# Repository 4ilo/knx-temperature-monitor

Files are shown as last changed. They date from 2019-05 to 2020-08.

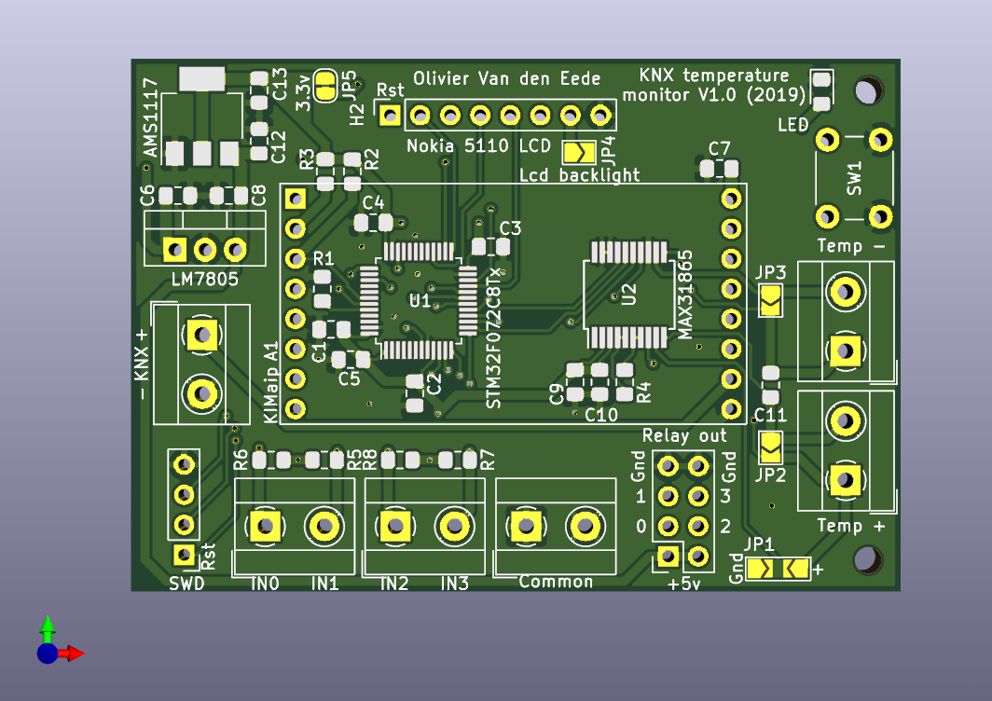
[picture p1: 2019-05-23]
pcb_v1.1/pcb.png

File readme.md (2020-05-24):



# KNX temperature monitor

Custom Pt100 temperature probe interface to KNX.

This module will be used to monitor my pool temperature, and generate alarms if the pump, water treatement or the pool heating stops.

### Features
- STM32F0 microcontroller
- On module LCD temperature readout (Nokia 5110 Lcd)
- Tapko KIMaip KNX bus interface module
- MAX31865 RTD-to-Digital Converter
- Extra binary I/O

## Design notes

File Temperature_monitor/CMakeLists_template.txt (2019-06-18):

#${templateWarning}
SET(CMAKE_SYSTEM_NAME Generic)
SET(CMAKE_SYSTEM_VERSION 1)
cmake_minimum_required(VERSION 3.7)

# specify cross compilers and tools
SET(CMAKE_C_COMPILER_WORKS 1)
SET(CMAKE_C_COMPILER arm-none-eabi-gcc)
SET(CMAKE_CXX_COMPILER_WORKS 1)
SET(CMAKE_CXX_COMPILER arm-none-eabi-g++)
set(CMAKE_ASM_COMPILER  arm-none-eabi-gcc)
set(CMAKE_AR arm-none-eabi-ar)
set(CMAKE_OBJCOPY arm-none-eabi-objcopy)
set(CMAKE_OBJDUMP arm-none-eabi-objdump)
set(SIZE arm-none-eabi-size)

SET(LINKER_SCRIPT $${CMAKE_SOURCE_DIR}/${linkerScript})

#Uncomment for hardware floating point
#SET(FPU_FLAGS "-mfloat-abi=hard -mfpu=fpv4-sp-d16")
#add_definitions(-DARM_MATH_CM4 -DARM_MATH_MATRIX_CHECK -DARM_MATH_ROUNDING -D__FPU_PRESENT=1)

#Uncomment for software floating point
#SET(FPU_FLAGS "-mfloat-abi=soft")

SET(COMMON_FLAGS
    "-mcpu=${mcpu} $${FPU_FLAGS} -mthumb -mthumb-interwork -ffunction-sections -fdata-sections \
    -g -fno-common -fmessage-length=0 ${linkerFlags} -u _printf_float")

SET(CMAKE_CXX_FLAGS_INIT "$${COMMON_FLAGS} -std=c++11")
SET(CMAKE_C_FLAGS_INIT "$${COMMON_FLAGS} -std=gnu99")
SET(CMAKE_EXE_LINKER_FLAGS_INIT "-Wl,-gc-sections,--print-memory-usage -T $${LINKER_SCRIPT}")

PROJECT(${projectName} C CXX ASM)
set(CMAKE_CXX_STANDARD 11)

#add_definitions(-DARM_MATH_CM4 -DARM_MATH_MATRIX_CHECK -DARM_MATH_ROUNDING -D__FPU_PRESENT=1)
add_definitions(${defines})

file(GLOB_RECURSE SOURCES ${sources})

include_directories(${includes})

add_executable($${PROJECT_NAME}.elf $${SOURCES} $${LINKER_SCRIPT})

set(CMAKE_EXE_LINKER_FLAGS
    "$${CMAKE_EXE_LINKER_FLAGS} -Wl,-Map=$${PROJECT_BINARY_DIR}/$${PROJECT_NAME}.map")

set(HEX_FILE $${PROJECT_BINARY_DIR}/$${PROJECT_NAME}.hex)
set(BIN_FILE $${PROJECT_BINARY_DIR}/$${PROJECT_NAME}.bin)

add_custom_command(TARGET $${PROJECT_NAME}.elf POST_BUILD
        COMMAND $${CMAKE_OBJCOPY} -Oihex $<TARGET_FILE:$${PROJECT_NAME}.elf> $${HEX_FILE}
        COMMAND $${CMAKE_OBJCOPY} -Obinary $<TARGET_FILE:$${PROJECT_NAME}.elf> $${BIN_FILE}
        COMMENT "Building $${HEX_FILE}
Building $${BIN_FILE}")

add_custom_target(UPLOAD
        arm-none-eabi-gdb -iex "target remote tcp:127.0.0.1:3333"
        -iex "monitor program $<TARGET_FILE:$${PROJECT_NAME}.elf>"
        -iex "monitor reset init"
        -iex "disconnect" -iex "quit")

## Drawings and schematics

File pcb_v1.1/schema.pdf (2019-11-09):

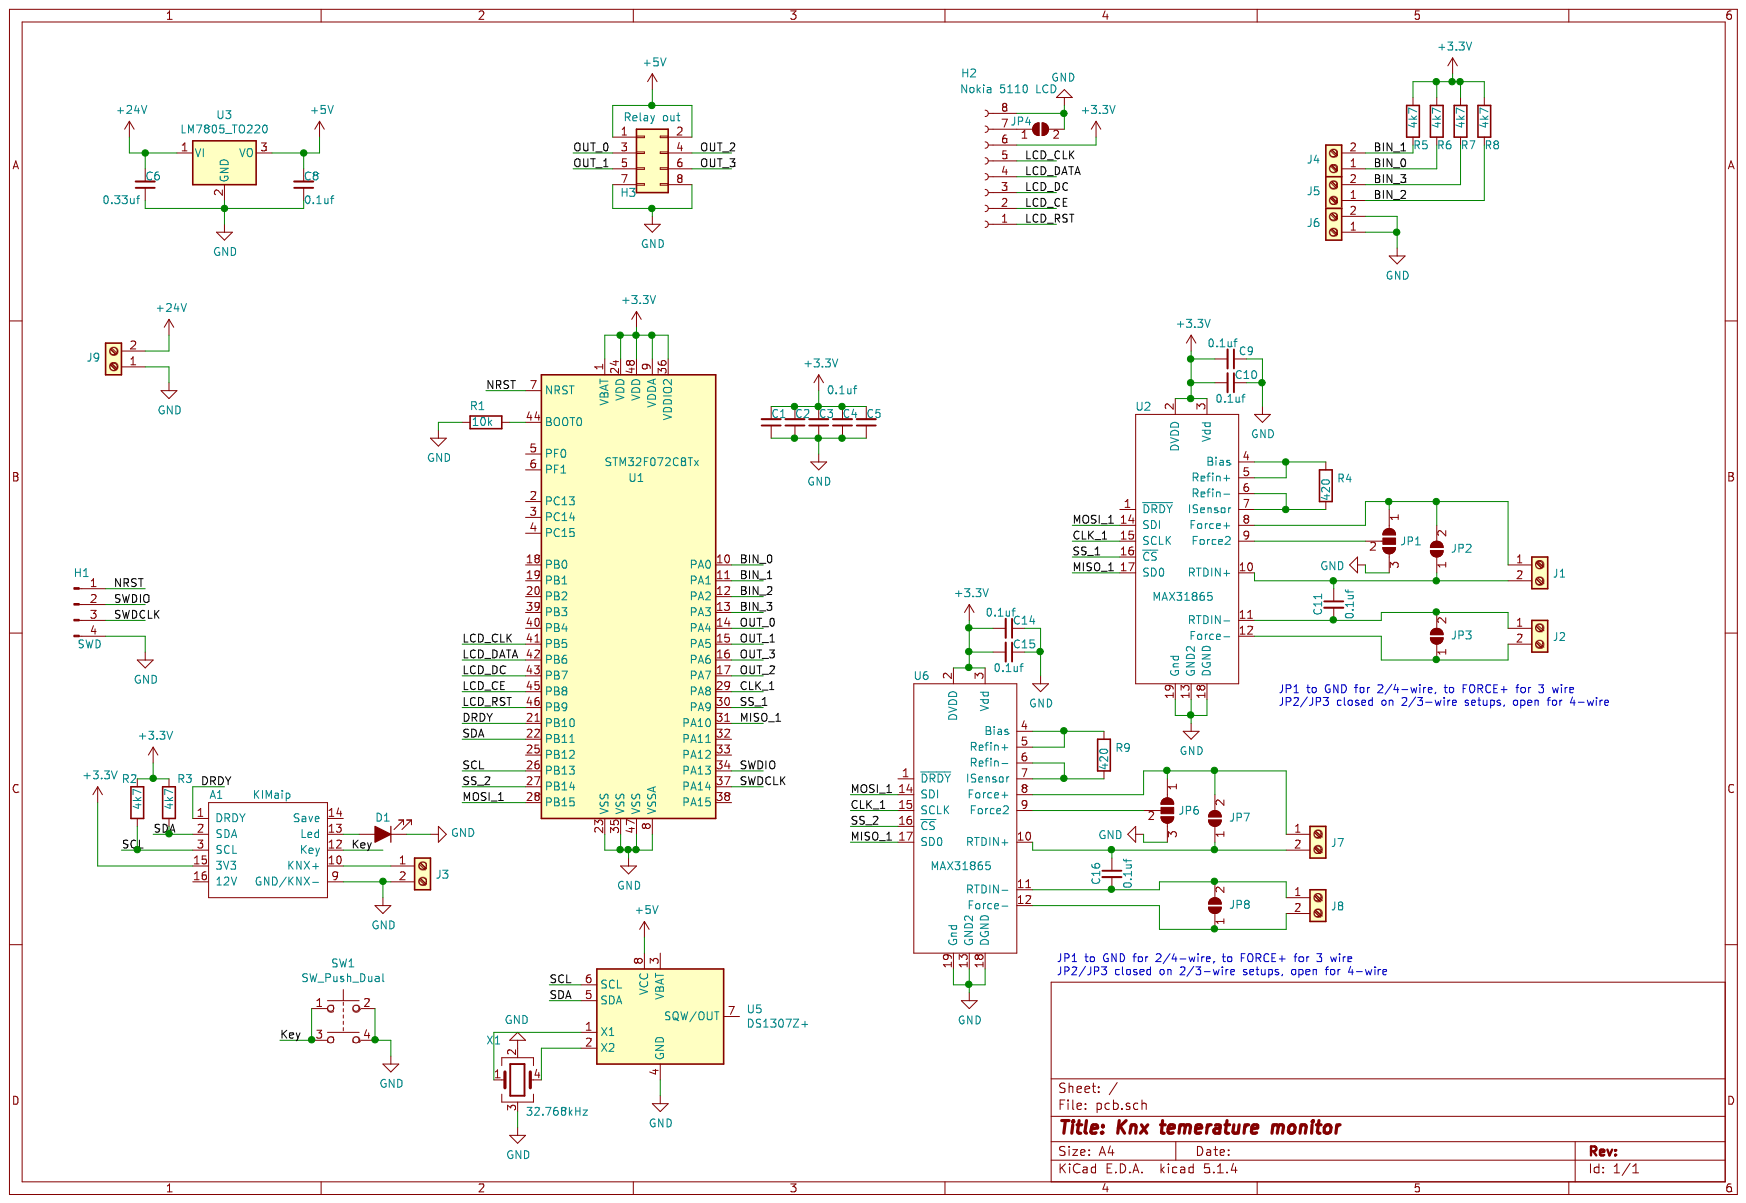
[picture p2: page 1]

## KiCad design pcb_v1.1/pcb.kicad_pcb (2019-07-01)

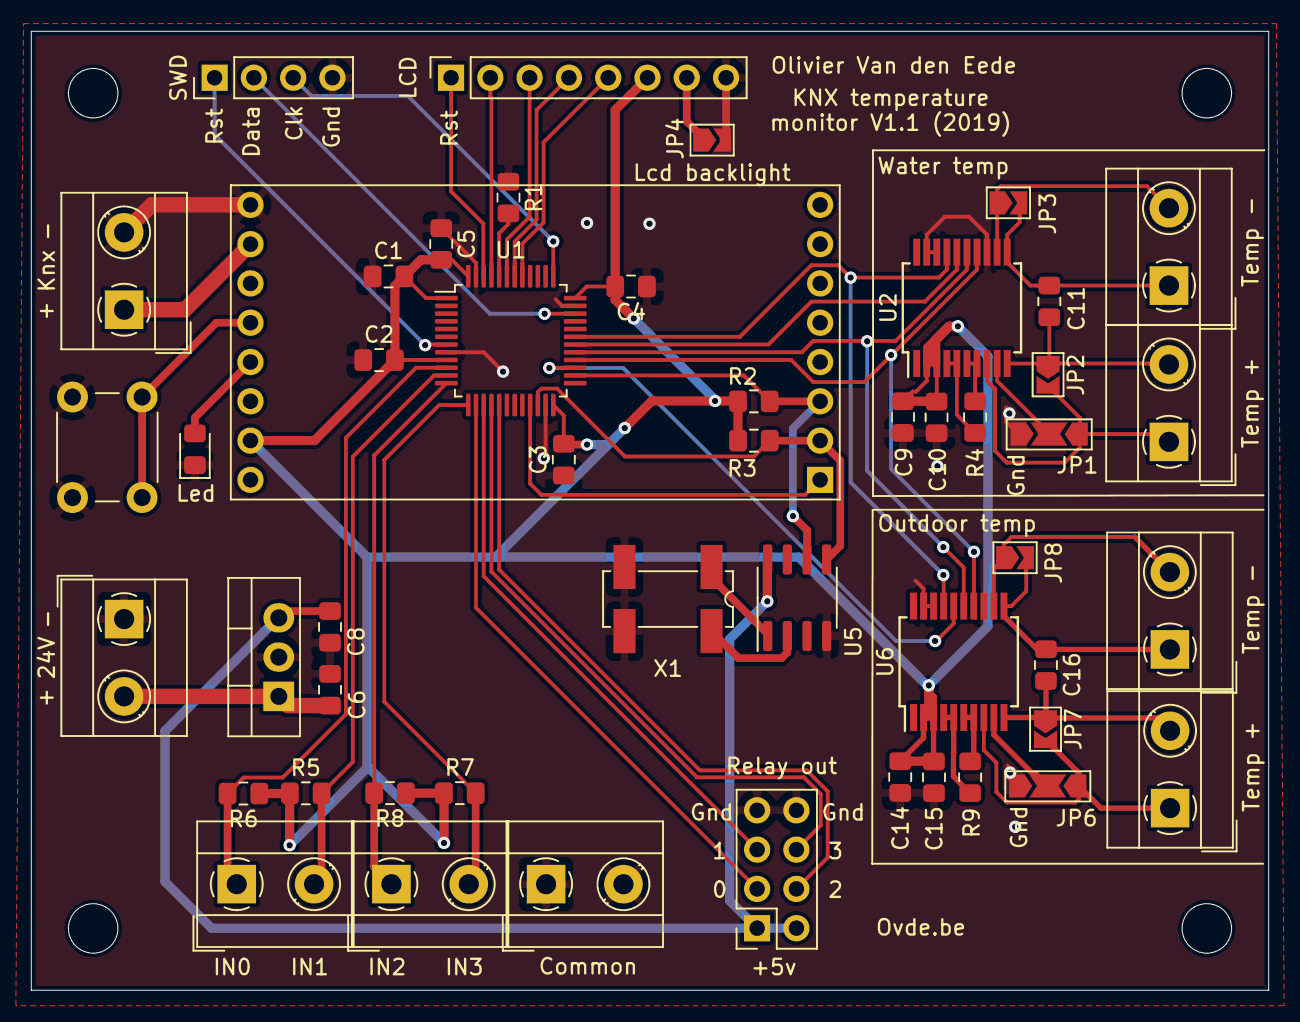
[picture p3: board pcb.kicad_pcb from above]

Board: 2 copper layers, 80.0 x 62.0 mm, 50 parts (0 on the bottom side), 49 nets.

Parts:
24V: 24v; TerminalBlock_MetzConnect_Type055_RT01502HDWU_1x02_P5.00mm_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
A1: KIMaip
C1, C2, C3, C4, C5, C8, C9, C10, C11, C14, C15, C16: 0.1uf; C_0805_2012Metric_Pad1.15x1.40mm_HandSolder
C6: 0.33uf; C_0805_2012Metric_Pad1.15x1.40mm_HandSolder
Common: Screw_Terminal_01x02; TerminalBlock_MetzConnect_Type055_RT01502HDWU_1x02_P5.00mm_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
J4, J5: Screw_Terminal_01x02; TerminalBlock_MetzConnect_Type055_RT01502HDWU_1x02_P5.00mm_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
JP1, JP6: SolderJumper_3_Open; SolderJumper-3_P2.0mm_Open_TrianglePad1.0x1.5mm_NumberLabels
JP2, JP3, JP4, JP7, JP8: SolderJumper_2_Open; SolderJumper-2_P1.3mm_Open_TrianglePad1.0x1.5mm
Knx: Knx; TerminalBlock_MetzConnect_Type055_RT01502HDWU_1x02_P5.00mm_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
LCD: Nokia 5110 LCD; PinSocket_1x08_P2.54mm_Vertical
Led: LED_ALT; LED_0805_2012Metric_Pad1.15x1.40mm_HandSolder
R1: 10k; R_0805_2012Metric_Pad1.15x1.40mm_HandSolder
R2, R3, R5, R6, R7, R8: 4k7; R_0805_2012Metric_Pad1.15x1.40mm_HandSolder
R4, R9: 420; R_0805_2012Metric_Pad1.15x1.40mm_HandSolder
Relay out: Relay out; PinSocket_2x04_P2.54mm_Vertical
SW1: SW_Push_Dual; SW_PUSH_6mm
SWD: SWD; PinHeader_1x04_P2.54mm_Vertical
Temp +: Screw_Terminal_01x02; TerminalBlock_MetzConnect_Type055_RT01502HDWU_1x02_P5.00mm_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
Temp +#2: Screw_Terminal_01x02; TerminalBlock_MetzConnect_Type055_RT01502HDWU_1x02_P5.00mm_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
Temp -: Screw_Terminal_01x02; TerminalBlock_MetzConnect_Type055_RT01502HDWU_1x02_P5.00mm_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
Temp -#2: Screw_Terminal_01x02; TerminalBlock_MetzConnect_Type055_RT01502HDWU_1x02_P5.00mm_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
U1: STM32F072C8Tx; LQFP-48_7x7mm_P0.5mm
U2, U6: MAX31865; SSOP-20_5.3x7.2mm_P0.65mm
U3: LM7805_TO220; TO-220-3_Vertical
U5: DS1307Z+; SOIC-8_3.9x4.9mm_P1.27mm
X1: 32.768kHz; Crystal_SMD_SeikoEpson_MC306-4Pin_8.0x3.2mm_HandSoldering

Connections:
+3V3: A1.15, C1.2, C2.2, C3.2, C4.2, C5.2, C9.2, C10.2, C14.2, C15.2, LCD.6, R2.1, R3.1, R5.1, R6.1, R7.1, R8.1, U1.1, U1.9, U1.24, U1.36, U1.48, U2.2, U2.3, U6.2, U6.3
+5V: C8.2, Relay out.1, Relay out.2, U3.3, U5.8
+24V: 24V.2, C6.2, U3.1
/BIN_0: J4.1, R6.2, U1.10
/BIN_1: J4.2, R5.2, U1.11
/BIN_2: J5.1, R8.2, U1.12
/BIN_3: J5.2, R7.2, U1.13
/CLK_1: U1.29, U2.15, U6.15
/DRDY: A1.1, U1.21
/Key: A1.12, SW1.1
/LCD_CE: LCD.2, U1.45
/LCD_CLK: LCD.5, U1.41
/LCD_DATA: LCD.4, U1.42
/LCD_DC: LCD.3, U1.43
/LCD_RST: LCD.1, U1.46
/MISO_1: U1.31, U2.17, U6.17
/MOSI_1: U1.28, U2.14, U6.14
/NRST: SWD.1, U1.7
/OUT_0: Relay out.3, U1.14
/OUT_1: Relay out.5, U1.15
/OUT_2: Relay out.4, U1.17
/OUT_3: Relay out.6, U1.16
/SCL: A1.3, R2.2, U1.26, U5.6
/SDA: A1.2, R3.2, U1.22, U5.5
/SS_1: U1.30, U2.16
/SS_2: U1.27, U6.16
/SWDCLK: SWD.3, U1.37
/SWDIO: SWD.2, U1.34
GND: 24V.1, A1.9, C1.1, C2.1, C3.1, C4.1, C5.1, C6.1, C8.1, C9.1, C10.1, C14.1, C15.1, Common.1, Common.2, JP1.3, JP4.2, JP6.3, Knx.2, LCD.8, Led.1, R1.1, Relay out.7, Relay out.8, SW1.2, SWD.4, U1.8, U1.23, U1.35, U1.47, U2.13, U2.18, U2.19, U3.2, U5.4, U6.13, U6.18, U6.19, X1.2, X1.3
unnamed: A1.10, Knx.1
unnamed: A1.13, Led.2
unnamed: C11.1, JP2.1, Temp +.2, U2.10
unnamed: C11.2, JP3.2, Temp -.1, U2.11
unnamed: C16.1, JP7.1, Temp +#2.2, U6.10
unnamed: C16.2, JP8.2, Temp -#2.1, U6.11
unnamed: JP4.1, LCD.7
unnamed: JP1.1, JP2.2, Temp +.1, U2.8
unnamed: JP3.1, Temp -.2, U2.12
unnamed: JP6.1, JP7.2, Temp +#2.1, U6.8
unnamed: JP8.1, Temp -#2.2, U6.12
unnamed: JP1.2, U2.9
unnamed: JP6.2, U6.9
unnamed: R1.2, U1.44
unnamed: R4.1, U2.4, U2.5
unnamed: R4.2, U2.6, U2.7
unnamed: R9.1, U6.4, U6.5
unnamed: R9.2, U6.6, U6.7
unnamed: U5.1, X1.1
unnamed: U5.2, X1.4

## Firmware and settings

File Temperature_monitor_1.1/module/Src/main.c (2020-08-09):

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

/* Includes ------------------------------------------------------------------*/
#include "main.h"
#include "cmsis_os.h"

/* USER CODE BEGIN Includes */

#include "FreeRTOS.h"
#include "task.h"
#include "nokia5110_LCD.h"
#include "MAX31865.h"
#include "KIMaip.h"
#include "string.h"
#include "stdio.h"
#include "types.h"
#include "logic.h"

/* USER CODE END Includes */

I2C_HandleTypeDef hi2c2;
IWDG_HandleTypeDef hiwdg;

/* Definitions for defaultTask */
osThreadId_t defaultTaskHandle;
const osThreadAttr_t defaultTask_attributes = {
    .name = "defaultTask",
    .priority = (osPriority_t) osPriorityNormal,
    .stack_size = 128 * 4
};

struct context_t {
    input_values_t* input_values;
    output_values_t* output_values;
    KIMaip_ctx* kimaip_ctx;
};


// KNX communication objects
#define MAX_KNX_OBJECTS 8
CommunicationObject lux_value = {KIM_TYPE_FLOAT, 0};
CommunicationObject water_temp = {KIM_TYPE_FLOAT, 1};
CommunicationObject timer = {KIM_TYPE_BOOL, 2};
CommunicationObject alarm_temp_low = {KIM_TYPE_BOOL, 3};
CommunicationObject alarm_temp_high = {KIM_TYPE_BOOL, 4};
CommunicationObject alarm_230v = {KIM_TYPE_BOOL, 5};
CommunicationObject alarm_24v = {KIM_TYPE_BOOL, 6};
CommunicationObject pump_status = {KIM_TYPE_INT, 7};
CommunicationObject *knx_objects[MAX_KNX_OBJECTS] = {
    &lux_value,
    &water_temp,
    &timer,
    &alarm_temp_low,
    &alarm_temp_high,
    &alarm_230v,
    &alarm_24v,
    &pump_status,
};
KIMaip_ctx kimaip_ctx = {&hi2c2, MAX_KNX_OBJECTS, knx_objects};

input_values_t input_values;
output_values_t output_values;
struct context_t context = {
    .input_values = &input_values,
    .output_values = &output_values,
    .kimaip_ctx = &kimaip_ctx,
};

void SystemClock_Config(void);
static void MX_GPIO_Init(void);
static void MX_I2C2_Init(void);
static void MX_IWDG_Init(void);
void StartDefaultTask(void *argument);

/* USER CODE BEGIN PFP */

int8_t init_lcd(void)
{
    LCD_setRST(LCD_RST_GPIO_Port, LCD_RST_Pin);
    LCD_setDC(LCD_DC_GPIO_Port, LCD_DC_Pin);
    LCD_setCE(LCD_CE_GPIO_Port, LCD_CE_Pin);
    LCD_setCLK(LCD_CLK_GPIO_Port, LCD_CLK_Pin);
    LCD_setDATA(LCD_DATA_GPIO_Port, LCD_DATA_Pin);
    LCD_init();

    return 0;
}

void lcdThread(void* data)
{
    struct context_t* context = (struct context_t*) data;

    char buffer[30] = "";
    while(1)
    {
        LCD_clear();

        snprintf(buffer, 30, "Tw: %.2f", context->input_values->water_temp);
        LCD_print(buffer, 0, 0);

        snprintf(buffer, 30, "To: %.2f", context->input_values->outside_temp);
        LCD_print(buffer, 0, 1);

        snprintf(buffer, 30, "Lux: %ld", context->input_values->lux);
        LCD_print(buffer, 0, 2);

        snprintf(buffer, 30, "IN : %d %d / %d", context->input_values->power_230v, context->input_values->power_24v, context->input_values->pump_active);
        LCD_print(buffer, 0, 4);

        snprintf(buffer, 30, "OUT: %d %d %d %d", context->output_values->pump_low, context->output_values->pump_high, context->output_values->tracing, context->output_values->cover_open);
        LCD_print(buffer, 0, 5);

        osDelay(500);
    }
}

void read_inputs(input_values_t* input_values, MAX31865_GPIO* sens_outside, MAX31865_GPIO* sens_water, KIMaip_ctx* kimaip)
{
    // Read digital inputs
    input_values->power_230v = HAL_GPIO_ReadPin(BIN_0_GPIO_Port, BIN_0_Pin) ? 0 : 1;
    input_values->power_24v = HAL_GPIO_ReadPin(BIN_1_GPIO_Port, BIN_1_Pin) ? 0 : 1;
    input_values->pump_active = HAL_GPIO_ReadPin(BIN_3_GPIO_Port, BIN_3_Pin) ? 0 : 1;

    // Read temperature
    input_values->water_temp = MAX31865_readTemp(sens_water);
    osDelay(50);
    input_values->outside_temp = MAX31865_readTemp(sens_outside);

    // Read KNX values
    input_values->lux = kimaip->objects[0]->Float;
    input_values->timer = kimaip->objects[2]->Bool;
}

void set_outputs(output_values_t* output_values)
{
    HAL_GPIO_WritePin(OUT_0_GPIO_Port, OUT_0_Pin, output_values->pump_low ? 0 : 1);
    HAL_GPIO_WritePin(OUT_1_GPIO_Port, OUT_1_Pin, output_values->pump_high ? 0 : 1);
    HAL_GPIO_WritePin(OUT_2_GPIO_Port, OUT_2_Pin, output_values->tracing ? 0 : 1);
    HAL_GPIO_WritePin(OUT_3_GPIO_Port, OUT_3_Pin, output_values->cover_open ? 0 : 1);
}

void send_knx(input_values_t* input_values, output_values_t* output_values, KIMaip_ctx* kimaip_ctx)
{
    static uint8_t counter = 0;
    uint8_t pump_status = 0;

    #define MAX_COM 5
    static uint8_t last_values[MAX_COM] = {0};
    const uint8_t com_objs[MAX_COM] = {3, 4, 5, 6, 7};

    if (counter >= 10) {
        const uint8_t* values[MAX_COM] = {
            &output_values->alarm_temp_low,
            &output_values->alarm_temp_high,
            &output_values->alarm_230v,
            &output_values->alarm_24v,
            &pump_status,
        };
        pump_status =  (output_values->pump_low ? 1 : 0) + output_values->pump_high;
        if (pump_status && input_values->pump_active == 0) {
            // Pump is driven, but motor drive did not activate
            pump_status = 3;
        }

        // Send alarms and pump status
        for (uint8_t i = 0; i < MAX_COM; i++) {
            if (*values[i] != last_values[i]) {
                KIMaip_Send_Int(kimaip_ctx, *values[i], com_objs[i]);
                last_values[i] = *values[i];
            }
        }

        // Send temp
        KIMaip_Send_Float(kimaip_ctx, input_values->water_temp, 1);

        counter = 0;
    }

    counter++;
}

void StartDefaultTask(void *argument)
{
    struct context_t* context = (struct context_t*) argument;

    // Set both chip select lines high
    HAL_GPIO_WritePin(SS_1_GPIO_Port, SS_1_Pin, 1);
    HAL_GPIO_WritePin(SS_2_GPIO_Port, SS_2_Pin, 1);

    // Init outside temp sens
    MAX31865_GPIO sens_outside = {
        .CE_PORT = SS_2_GPIO_Port,
        .CE_PIN = SS_2_Pin,
        .CLK_PORT = CLK_1_GPIO_Port,
        .CLK_PIN = CLK_1_Pin,
        .MOSI_PORT = MOSI_1_GPIO_Port,
        .MOSI_PIN = MOSI_1_Pin,
        .MISO_PORT = MISO_1_GPIO_Port,
        .MISO_PIN = MISO_1_Pin,
        .counter = 0,
        .moving_average = 0,
        .value = 20,
    };
    MAX31865_init(&sens_outside, 2);

    // Init water temp sens
    MAX31865_GPIO sens_water = {
        .CE_PORT = SS_1_GPIO_Port,
        .CE_PIN = SS_1_Pin,
        .CLK_PORT = CLK_1_GPIO_Port,
        .CLK_PIN = CLK_1_Pin,
        .MOSI_PORT = MOSI_1_GPIO_Port,
        .MOSI_PIN = MOSI_1_Pin,
        .MISO_PORT = MISO_1_GPIO_Port,
        .MISO_PIN = MISO_1_Pin,
        .counter = 0,
        .moving_average = 0,
        .value = 20,
    };
    MAX31865_init(&sens_water, 2);


    while(1)
    {
        // Read inputs
        read_inputs(context->input_values, &sens_outside, &sens_water, context->kimaip_ctx);

        // Logic
        run_logic(context->input_values, context->output_values);

        // Set outputs
        set_outputs(context->output_values);

        // Send to knx
        send_knx(context->input_values, context->output_values, context->kimaip_ctx);

        HAL_IWDG_Refresh(&hiwdg);
        osDelay(1000);
    }
}

/* USER CODE END PFP */

/**
 * @brief  The application entry point.
 * @retval int
 */
int main(void)
{
    /* MCU Configuration--------------------------------------------------------*/

    /* Reset of all peripherals, Initializes the Flash interface and the Systick. */
    HAL_Init();

    /* Configure the system clock */
    SystemClock_Config();

    /* Initialize all configured peripherals */
    MX_GPIO_Init();
    MX_I2C2_Init();
    MX_IWDG_Init();
    /* USER CODE BEGIN 2 */

    init_lcd();
    LCD_print("Boot", 0, 0);
    HAL_Delay(1000);

    /* USER CODE END 2 */

    /* Init scheduler */
    osKernelInitialize();

    /* USER CODE BEGIN RTOS_MUTEX */
    /* add mutexes, ... */
    /* USER CODE END RTOS_MUTEX */

    /* USER CODE BEGIN RTOS_SEMAPHORES */
    /* add semaphores, ... */
    /* USER CODE END RTOS_SEMAPHORES */

    /* USER CODE BEGIN RTOS_TIMERS */
    /* start timers, add new ones, ... */
    /* USER CODE END RTOS_TIMERS */

    /* USER CODE BEGIN RTOS_QUEUES */
    /* add queues, ... */
    /* USER CODE END RTOS_QUEUES */
    /* Create the thread(s) */
    /* creation of defaultTask */
    defaultTaskHandle = osThreadNew(StartDefaultTask, (void*)&context, &defaultTask_attributes);
    TaskHandle_t lcdThread_handle = NULL;
    xTaskCreate(lcdThread, "LCD", 128*4, (void*)&context, 1, &lcdThread_handle);

    /* USER CODE BEGIN RTOS_THREADS */
    /* add threads, ... */
    /* USER CODE END RTOS_THREADS */

    /* Start scheduler */
    osKernelStart();

    /* We should never get here as control is now taken by the scheduler */
    /* Infinite loop */
    /* USER CODE BEGIN WHILE */
    while (1)
    {
        /* USER CODE END WHILE */

        /* USER CODE BEGIN 3 */
    }
    /* USER CODE END 3 */
}

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
/* USER CODE BEGIN Header_StartDefaultTask */

/**
 * @brief  Period elapsed callback in non blocking mode
 * @note   This function is called  when TIM1 interrupt took place, inside
 * HAL_TIM_IRQHandler(). It makes a direct call to HAL_IncTick() to increment
 * a global variable "uwTick" used as application time base.
 * @param  htim : TIM handle
 * @retval None
 */
void HAL_TIM_PeriodElapsedCallback(TIM_HandleTypeDef *htim)
{
    if (htim->Instance == TIM1) {
        HAL_IncTick();
    }
}

void HAL_GPIO_EXTI_Callback(uint16_t GPIO_Pin)
{
    if (GPIO_Pin == DRDY_Pin)
    {
        KIMaip_Handle_Interrupt(&kimaip_ctx);
    }
}

/**
 * @brief  This function is executed in case of error occurrence.
 * @retval None
 */
void Error_Handler(void)
{
    /* USER CODE BEGIN Error_Handler_Debug */
    /* User can add his own implementation to report the HAL error return state */

    /* USER CODE END Error_Handler_Debug */
}

#ifdef  USE_FULL_ASSERT
/**
 * @brief  Reports the name of the source file and the source line number
 *         where the assert_param error has occurred.
 * @param  file: pointer to the source file name
 * @param  line: assert_param error line source number
 * @retval None
 */
void assert_failed(uint8_t *file, uint32_t line)
{ 
    /* USER CODE BEGIN 6 */
    /* User can add his own implementation to report the file name and line number,
tex: printf("Wrong parameters value: file %s on line %d\r\n", file, line) */
    /* USER CODE END 6 */
}
#endif /* USE_FULL_ASSERT */

/************************ (C) COPYRIGHT STMicroelectronics *****END OF FILE****/

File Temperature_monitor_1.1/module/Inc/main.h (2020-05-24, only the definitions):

#define BIN_0_Pin GPIO_PIN_0
#define BIN_0_GPIO_Port GPIOA
#define BIN_1_Pin GPIO_PIN_1
#define BIN_1_GPIO_Port GPIOA
#define BIN_2_Pin GPIO_PIN_2
#define BIN_2_GPIO_Port GPIOA
#define BIN_3_Pin GPIO_PIN_3
#define BIN_3_GPIO_Port GPIOA
#define OUT_0_Pin GPIO_PIN_4
#define OUT_0_GPIO_Port GPIOA
#define OUT_1_Pin GPIO_PIN_5
#define OUT_1_GPIO_Port GPIOA
#define OUT_3_Pin GPIO_PIN_6
#define OUT_3_GPIO_Port GPIOA
#define OUT_2_Pin GPIO_PIN_7
#define OUT_2_GPIO_Port GPIOA
#define DRDY_Pin GPIO_PIN_10
#define DRDY_GPIO_Port GPIOB
#define SS_2_Pin GPIO_PIN_14
#define SS_2_GPIO_Port GPIOB
#define MOSI_1_Pin GPIO_PIN_15
#define MOSI_1_GPIO_Port GPIOB
#define CLK_1_Pin GPIO_PIN_8
#define CLK_1_GPIO_Port GPIOA
#define SS_1_Pin GPIO_PIN_9
#define SS_1_GPIO_Port GPIOA
#define MISO_1_Pin GPIO_PIN_10
#define MISO_1_GPIO_Port GPIOA
#define LCD_CLK_Pin GPIO_PIN_5
#define LCD_CLK_GPIO_Port GPIOB
#define LCD_DATA_Pin GPIO_PIN_6
#define LCD_DATA_GPIO_Port GPIOB
#define LCD_DC_Pin GPIO_PIN_7
#define LCD_DC_GPIO_Port GPIOB
#define LCD_CE_Pin GPIO_PIN_8
#define LCD_CE_GPIO_Port GPIOB
#define LCD_RST_Pin GPIO_PIN_9
#define LCD_RST_GPIO_Port GPIOB

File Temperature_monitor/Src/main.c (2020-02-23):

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

/* Includes ------------------------------------------------------------------*/
#include "main.h"

/* USER CODE BEGIN Includes */

#include "nokia5110_LCD.h"
#include "MAX31865.h"
#include "KIMaip.h"

/* USER CODE END Includes */

/* USER CODE BEGIN PTD */

#define MAX_INPUTS 5
#define MAX_OUTPUTS 5
typedef struct {
    uint8_t size;
    uint16_t pins[MAX_INPUTS];
    GPIO_TypeDef *ports[MAX_INPUTS];
    uint16_t objectNrs[MAX_INPUTS];

    uint8_t data[MAX_INPUTS];
} binaryInData;

typedef struct {
    uint8_t size;
    uint16_t pins[MAX_OUTPUTS];
    GPIO_TypeDef *ports[MAX_OUTPUTS];
    CommunicationObject *communicationObjects[MAX_OUTPUTS];
} binaryOutData;

/* USER CODE END PTD */

/* USER CODE BEGIN PD */

#define BIN_INPUTS 4
#define BIN_OUTPUTS 4

/* USER CODE END PD */

I2C_HandleTypeDef hi2c1;

IWDG_HandleTypeDef hiwdg;

/* USER CODE BEGIN PV */

// KIMaip communication objects
CommunicationObject b_out0 = {KIM_TYPE_BOOL, 0};
CommunicationObject b_out1 = {KIM_TYPE_BOOL, 1};
CommunicationObject b_out2 = {KIM_TYPE_BOOL, 2};
CommunicationObject b_out3 = {KIM_TYPE_BOOL, 3};
CommunicationObject illumination = {KIM_TYPE_FLOAT, 9};
CommunicationObject *objects[5] = {&b_out0, &b_out1, &b_out2, &b_out3, &illumination};
uint8_t object_count = 5;

/* USER CODE END PV */

void SystemClock_Config(void);
static void MX_GPIO_Init(void);
static void MX_I2C1_Init(void);
static void MX_IWDG_Init(void);
/* USER CODE BEGIN PFP */

void init_outputs(binaryOutData *b_out);
void validate_pool_temp(float temperature);

/* USER CODE END PFP */

/**
  * @brief  The application entry point.
  * @retval int
  */
int main(void)
{
  

  /* MCU Configuration--------------------------------------------------------*/

  /* Reset of all peripherals, Initializes the Flash interface and the Systick. */
  HAL_Init();

  /* Configure the system clock */
  SystemClock_Config();

  /* Initialize all configured peripherals */
  MX_GPIO_Init();
  MX_I2C1_Init();
  MX_IWDG_Init();
  /* USER CODE BEGIN 2 */

    // Init LCD
    LCD_setRST(LCD_RST_GPIO_Port, LCD_RST_Pin);
    LCD_setDC(LCD_DC_GPIO_Port, LCD_DC_Pin);
    LCD_setCE(LCD_CE_GPIO_Port, LCD_CE_Pin);
    LCD_setCLK(LCD_CLK_GPIO_Port, LCD_CLK_Pin);
    LCD_setDATA(LCD_DATA_GPIO_Port, LCD_DATA_Pin);
    LCD_init();

    // Init MAX31865
    MAX31865_GPIO max_gpio;
    max_gpio.MISO_PIN = MISO_1_Pin;
    max_gpio.MISO_PORT = MISO_1_GPIO_Port;
    max_gpio.MOSI_PIN = MOSI_1_Pin;
    max_gpio.MOSI_PORT = MOSI_1_GPIO_Port;
    max_gpio.CLK_PIN = CLK_1_Pin;
    max_gpio.CLK_PORT = CLK_1_GPIO_Port;
    max_gpio.CE_PIN = SS_1_Pin;
    max_gpio.CE_PORT = SS_1_GPIO_Port;
    MAX31865_init(&max_gpio, 3);

    float temperature, avg_temp = 0;

    binaryInData b_in = {
            BIN_INPUTS,                                                                 // Len
            {BIN_0_Pin, BIN_1_Pin, BIN_2_Pin, BIN_3_Pin},                               // GPIO pins
            {BIN_0_GPIO_Port, BIN_1_GPIO_Port, BIN_2_GPIO_Port, BIN_3_GPIO_Port},       // GPIO ports
            {4, 5, 6, 7}                                                                // Communication object numbers
    };

    binaryOutData b_out = {
            BIN_OUTPUTS,                                                                 // Len
            {OUT_0_Pin, OUT_1_Pin, OUT_2_Pin, OUT_3_Pin},                               // GPIO pins
            {OUT_0_GPIO_Port, OUT_1_GPIO_Port, OUT_2_GPIO_Port, OUT_3_GPIO_Port},       // GPIO ports
            {&b_out0, &b_out1, &b_out2, &b_out3}                                        // Communication objects
    };

    uint8_t send_temp_counter = 0;

  /* USER CODE END 2 */

  /* Infinite loop */
  /* USER CODE BEGIN WHILE */
    while (1)
    {
    /* USER CODE END WHILE */

    /* USER CODE BEGIN 3 */

        // Read temperature and show on screen, and send to bus
        temperature = MAX31865_readTemp();


        // Onlu send temp every 10 seconds
        if(send_temp_counter >= 10)
        {
            avg_temp = avg_temp / 10;
            KIMaip_Send_Float(avg_temp, 8);
            LCD_print_float(avg_temp, 2, 9, FONT_BIG);

            // Logic functions
            validate_pool_temp(avg_temp);

            send_temp_counter = 0;
            avg_temp = 0;
        }
        else
        {
            avg_temp += temperature;
            send_temp_counter++;
        }

        // Update output status
        for(uint8_t i = 0; i < b_out.size; i++)
        {
            HAL_GPIO_WritePin(b_out.ports[i], b_out.pins[i], b_out.communicationObjects[i]->Bool);
        }


        // Read binary inputs, and send to bus
        uint8_t temp;
        for(uint8_t i = 0; i < b_in.size; i++)
        {
            temp = !HAL_GPIO_ReadPin(b_in.ports[i], b_in.pins[i]);
            if (temp != b_in.data[i])
            {
                b_in.data[i] = temp;
                KIMaip_Send_Bool(b_in.data[i], b_in.objectNrs[i]);
            }
        }

        HAL_IWDG_Refresh(&hiwdg);
        HAL_Delay(1000);

    }
  /* USER CODE END 3 */
}

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
/* USER CODE BEGIN 4 */

void HAL_GPIO_EXTI_Callback(uint16_t GPIO_Pin)
{
    if(GPIO_Pin == DRDY_Pin)
    {
        KIMaip_Handle_Interrupt();
    }
}

void validate_pool_temp(float temperature)
{
    float temp_limit = 30.0;
    static uint8_t pool_too_hot = 0;

    if(temperature >= temp_limit && !pool_too_hot)
    {
        pool_too_hot = 1;
        KIMaip_Send_Bool(1, 10);
    }
    else if(temperature < (temp_limit-1) && pool_too_hot)
    {
        pool_too_hot = 0;
        KIMaip_Send_Bool(0, 10);
    }
}

/* USER CODE END 4 */
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


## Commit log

2019-05-20 start schematic
    [pcb.kicad_pcb, pcb.sch]
2019-05-21 schematic + pin layout
    [pcb.sch]
2019-05-21 assign footprints
    [pcb.sch]
2019-05-21 custom footprint
    [pcb.sch]
2019-05-22 pcb layout
    [pcb.sch]
2019-05-22 pcb routed
    [pcb.kicad_pcb, pcb.sch]
2019-05-22 pcb klaar
    [pcb.kicad_pcb]
2019-05-23 pcb ordered
    [pcb-B_Cu.gbr, pcb-B_Mask.gbr, pcb-B_SilkS.gbr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]
2019-06-18 lcd working
    [stm32f072.cfg]
2019-06-19 read binary inputs
    [stm32f072.cfg]
2019-06-20 bus communication
    [Kimaip communication object description.ods]
2019-06-20 add rdry trace to pcb
    [Kimaip communication object description.ods, pcb.kicad_pcb, pcb.sch]
2019-06-27 avg temperature fix
    [pcb-B_Cu.gbr, pcb-B_Mask.gbr, pcb-B_SilkS.gbr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]
2019-06-29 update schematic
    [pcb.sch]
2019-07-01 pcb v1.1 component placement
    [pcb.kicad_pcb, pcb.sch]
2019-07-01 pcb done
    [pcb-B_Cu.gbr, pcb-B_Mask.gbr, pcb-B_Paste.gbr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]
2019-11-09 hello world on board
    [stm32f072.cfg]
2020-02-23 add watchdog timer reset
    [Temperature_monitor.ioc, main.c]
2020-05-24 dockerized v1.1 build with freertos
    [stm32f072.cfg]
2020-08-02 set max31865 in reset state before init
    [main.c]
2020-08-03 Activate pump_low when pump_high is 1
2020-08-03 disable pump_low when pump_high is low
2020-08-04 send pump low/high to knx
2020-08-08 Send pump error status over bus
    [main.c]
2020-08-10 Don't reset alarm when pump is inactive

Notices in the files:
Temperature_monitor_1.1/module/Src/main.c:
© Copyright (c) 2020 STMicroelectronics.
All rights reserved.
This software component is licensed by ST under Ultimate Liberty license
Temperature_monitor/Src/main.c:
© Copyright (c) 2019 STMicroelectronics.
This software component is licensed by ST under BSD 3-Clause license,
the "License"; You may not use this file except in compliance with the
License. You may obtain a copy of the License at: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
